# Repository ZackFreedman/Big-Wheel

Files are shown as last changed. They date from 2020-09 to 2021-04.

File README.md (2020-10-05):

# Big Wheel
 3D-printed video control surface

Slapped together in a weekend by Zack Freedman of Voidstar Lab for [a YouTube video! Check it out!](https://www.youtube.com/watch?v=72a85tWOJVY)

Materials:
- 1x each of:
    - Big Ass-Wheel.stl
    - Body.stl
    - Wheel Insert.stl
- 1x of either of the following:
    - One print of Waffle Baseplate Combo.stl
    - One print of Support Waffle.stl and one laser-cut Big Wheel Baseplate.ai
- 7x 10mm M2.5 screws
- 6x M2.5 heat-set inserts, nominal 5mm length
- 1x M2.5 nut
- 14x Cherry MX-compatible keyswitches
- 14x keycaps for keyswitches
- 14x rectifier diodes, such as the 1N4004
- 4x PEC12-compatible rotary encoders with pushbutton, 15mm flatted shaft preferred
- 3x encoder knobs, max. diameter 22mm
- 6x rubber feet, thicker than the head of the M2.5 screws
- 1x Teensy LC, Teensy 3.x, or Teensy 4.0
- Zap-a-Gap or other adhesive that can bond your 3D-printing material
- Lots of wire and heatshrink

Instructions:
1. [Watch video](https://www.youtube.com/watch?v=72a85tWOJVY) to see construction overview
2. Fabricate 3D-printed and laser-cut parts
3. If using laser-cut Big Wheel Baseplate, glue Support Waffle onto the etched side of the Baseplate.
4. Snap keyswitches and encoders into Body
5. Using wiring diagram, build switch matrix. Take care to route wires away from surface that contacts Support Waffle.
6. Connect switch matrix and encoders to Teensy. Take care to leave extra wire!
7. Slide Teensy into its rails. It should fit snugly - if it's loose, add a bit of electrical tape to tighten things up.
8. Connect to computer, load firmware, and test
9. Using a soldering iron, apply heat-set inserts to the bosses on the Body.
10. Mount Waffle and Baseplate combo to the Body using the screws.
11. Apply rubber feet to Baseplate.
12. Slip nut into slot on Big Ass-Wheel and insert screw through side of wheel.
13. Mount Big Ass-Wheel on center encoder and tighten screw. It should turn smoothly but not wobble.
14. Glue Wheel Insert onto Big Ass-Wheel.
15. Mount remaining encoder knobs and keycaps.
16. If desired, modify firmware to bind your preferred commands to the controls.
17. Let Zack know you built the project!

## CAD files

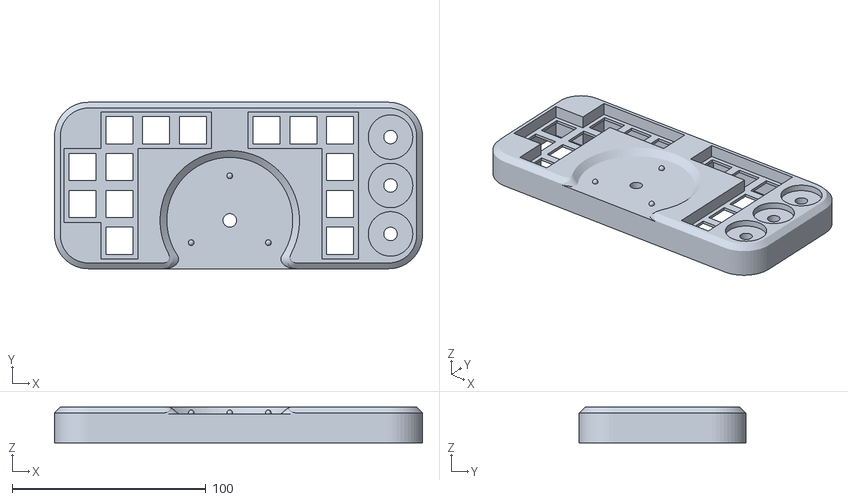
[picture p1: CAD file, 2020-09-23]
Body.stl
190.0 x 86.0 x 18.5

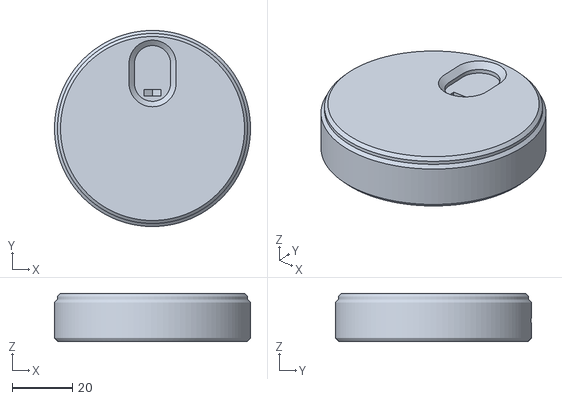
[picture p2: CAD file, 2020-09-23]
Big Ass-Wheel.stl
65.0 x 65.0 x 16.0

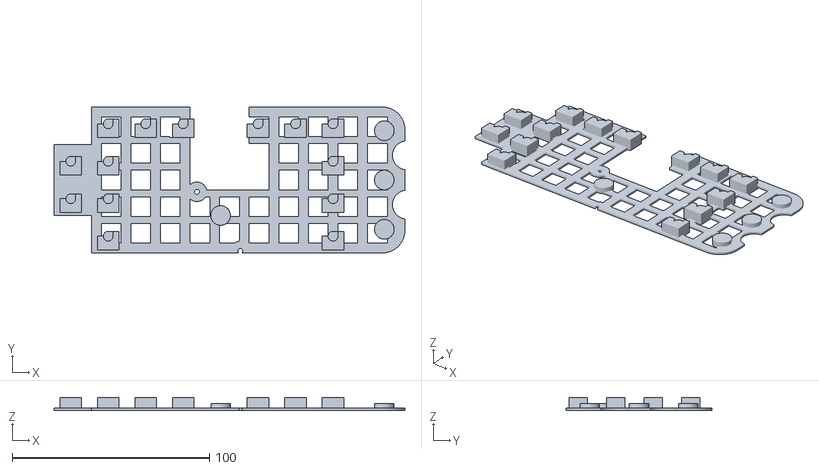
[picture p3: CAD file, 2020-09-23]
Support Waffle.stl
178.0 x 74.0 x 6.50

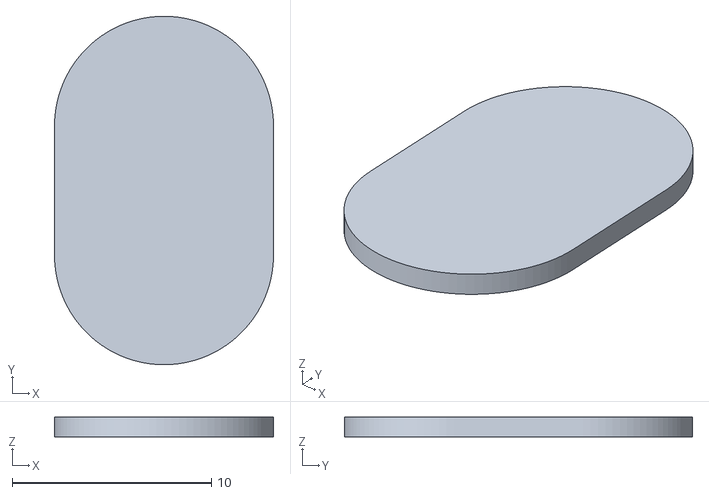
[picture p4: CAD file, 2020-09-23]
Wheel Insert.stl
11.0 x 17.5 x 1.00

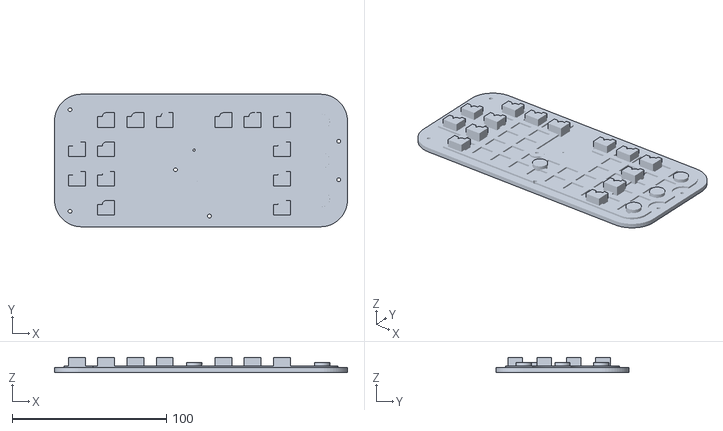
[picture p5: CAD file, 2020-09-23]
Waffle Baseplate Combo.stl
190.0 x 86.0 x 9.50

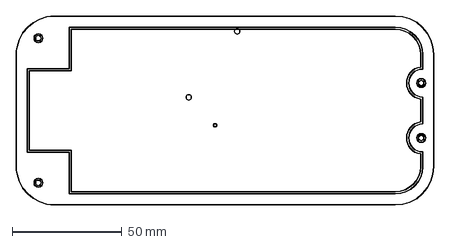
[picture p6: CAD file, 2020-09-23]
Big Wheel Baseplate.dxf
190.0 x 86.0 mm

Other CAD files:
Big Wheel model.f3d

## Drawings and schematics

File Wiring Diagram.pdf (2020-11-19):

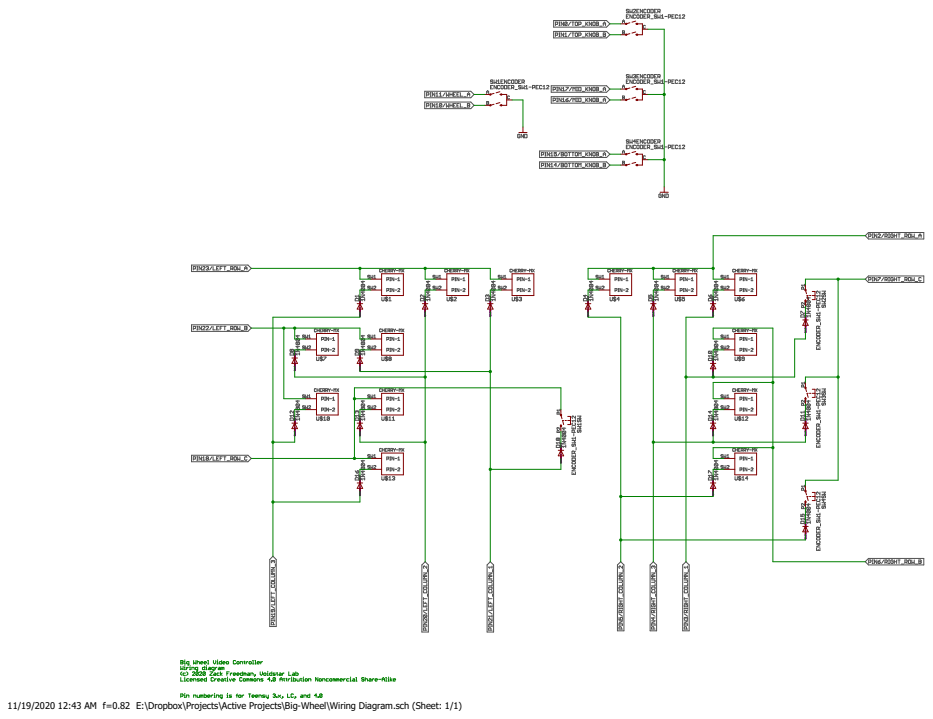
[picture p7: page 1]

11/19/2020 12:43 AM f=0.82 E:\Dropbox\Projects\Active Projects\Big-Wheel\Wiring Diagram.sch (Sheet: 1/1)

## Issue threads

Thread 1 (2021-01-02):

Why wire a keyboard matrix instead of connecting each key to it own Teensy pin?

lvisintini, 2021-01-02:
Hi there @ZackFreedman,

I noticed that you did a keyboard matrix wiring diagram for this project.
After seeing your Teensy video overview I realized I do not understand why you made that design choice, as It would appear that the Teensy has enough digital pins to "service" each of the 14 keys separately.

I think the main benefit of using a matrix is that it reduces the amount of digital pins required to service X number of keys at the cost of making the wiring more complex and requiring diodes to avoid key ghosting.

Given you were time constrained, would it not have been simpler to wire each key directly?

I am only a beginner as far as electronics go, so this question comes out comes a bit out of ignorance and beginner-level research. Apologies in advance for that.

I really your videos. I find them inspiring. Keep them coming.

Cheers

Lvisintini

Liam26, 2021-01-07:
@lvisintini,

I am (obviously) not @ZackFreedman but I thought I might weigh in with my opinion here as to some reasons why he might of done this. Now they may not be correct at all so I’ll be more than happy to be corrected if I’m wrong but here it goes.

Yes it does make the wiring diagram more complex, however, it does drastically reduce the amount of total wires needed. Now this can save you two things mainly:

Time - having fewer wires means less overalls soldering, and the complexity ‘shouldn’t’ really matter if you are following a diagram like Zack was. Therefore less time soldering/faffing more chance of a finished project. (Which is what Zach is saying all the time in his videos, better to ‘cut’ corners and save time to end up with a finished product, rather than it never getting finished!)

Space - this one is a big one for this situation I think, he specifically mentions in his video that he almost had trouble fitting all the wires in with just what he had. Now if he used all the extra wires to make the soldering (and I suppose programming) easier, he might not have gotten it to fit, or possible even had to print a thicker enclosure costing him far more time than just sketching up a matrix diagram before he got the the wiring!

That’s just my thinking around it, so you’re not wrong the teensy could have done it with the amount of pins it had, but the benefits of a matrix in this situation (outlined above) outweighs the downsides (what you stated with the increased wiring complexity)

Anyway it might not have been anything I’ve said I’m only guessing from my point of view so if Zach does get to see this and reply I would be very interested in knowing if these were the reasons or if I’m totally off the mark! But either way I thought I’d share with you as you’d made the effort to ask!

Hope this helps in some way,
Liam

lvisintini, 2021-01-23:
Hi @Liam26. Thanks for this.
I had another look at the cable management in the video and I believe that you are right in both accounts. :)
THX

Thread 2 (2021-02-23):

Teensy collision with mounting stud

kimmellr, 2021-02-23:
There is a collision with the teensy and the venter mounting pose when installing the board.
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

Changing d236 to 16mm should solve this problem with out any conflicts.

Any thoughts?

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

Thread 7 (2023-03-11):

Deletion of lastknobposition for certain knobs

tjseydel, 2023-03-11:
I just finished the build of the keyboard. Thanks for providing all the files @ZackFreedman! It was really fun to make and I learned a lot! =D

When testing the firmware I encountered some unexpected behavior where addition keys were pressed when pressing one of the keys. Also, the top and middle wheels seemed not to be working.

For anyone encountering the same issue, I located where the problem arose. Somehow the lastKnobPositions array values were deleted for the top and middle wheel/encoder which causes repeated execution of these linked knobs and thus additional key presses with every key I pressed.

The array values were deleted in lines 580 & 581:
  for (int i = 0; i < 6; i++)
    lastKnobDeltas[i] = knobDeltas[i];

These lines are not used and can be commented out/deleted to fix the problem.

I have absolutely no idea why these lines cause the array values to be deleted, so if anyone knows, please let me know. I am very curious to see what is causing it.

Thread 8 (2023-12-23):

VBoxMouse.sys crash the PC when unplug USB cable

janxfi, 2023-12-23:
If you have or have ever had Virtualbox installed, when you remove Teensy from the computer, the whole computer crashes. OS is Windows 10.

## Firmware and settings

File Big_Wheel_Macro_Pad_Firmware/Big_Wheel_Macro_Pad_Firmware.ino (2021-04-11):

/*
   "Big Wheel" macro pad firmware
   Copyright Sept. 2020 Zack Freedman of Voidstar Lab
   Licensed Creative Commons 4.0 Noncommercial Share-Alike

   This code is designed to run on this hardware: https://github.com/ZackFreedman/Big-Wheel
   This was used in a YouTube video! Check it out! https://www.youtube.com/watch?v=72a85tWOJVY

   Intended for Teensy LC, but should also work on Teensy 3.X and maybe Teensy 4.0
   These hotkeys and shortcuts are designed to control Premiere Pro, but you do you fam

   REMEMBER: Tools --> USB Type --> Serial + Keyboard + Mouse + Joystick
*/


#include <Encoder.h>
#include "actions.h"
#include "pins.h"

//#define DEBUG_DUMP_EVENTS
//#define DEBUG_DUMP_MATRIX
//#define DEBUG_DUMP_WHEEL_SPEED
//#define DEBUG_PLOT_WHEEL_SPEED
//#define DEBUG_SHUTTLE

Encoder topKnob(topKnobA, topKnobB);
Encoder middleKnob(middleKnobA, middleKnobB);
Encoder lowerKnob(lowerKnobA, lowerKnobB);
Encoder wheel(wheelA, wheelB);

long lastKnobPositions[4] = {0, 0, 0, 0};
int lastKnobDeltas[4];
bool lastSwitchStates[18];
bool debouncedSwitchStates[18];
bool lastDebouncedSwitchStates[18];
elapsedMillis switchDebounceTimestamps[18];
#define switchDebounceTime 50

int lastActions[6];
int allActionsThisFrame[6];
byte actionIndex = 0;

// Used to calculate rotational velocity of big wheel
// 1 detent = 4 pulses in the same direction
// 1 delta = Time between two successive detents, in ms
#define wheelDetentDeltaAverageCount 5  // More detents = smoother but laggier shuttling

// How many ms must elapse without wheel motion before resetting velocity measurements
// wheelTimeout must be > 1000.0 / max(abs(minimumDpsForReverse), minimumDpsForPlay)
#define wheelTimeout 50

// More detents = more predictable but laggier shuttling.
// minimumWheelDetentsToAverage must be <= wheelDetentDeltaAverageCount!
#define minimumWheelDetentsToAverage 2

elapsedMillis timeSinceLastWheelDetent;
long wheelDetentDeltas[wheelDetentDeltaAverageCount];
byte wheelDetentDeltaIndex;  // Used to treat wheelDetentDeltas as a circular buffer
float averageWheelDetentDelta;

// Shuttle states. In normal mode, one big knob detent (4 pulses) moves by 1 frame.
// In other states, a shuttle movement (Hotkeys J or K in Premiere) is in effect.
#define NO_STATE -255 // Shuttle state should never be this
#define STATE_TRIPLE_REVERSE -3
#define STATE_DOUBLE_REVERSE -2
#define STATE_REVERSE -1
#define STATE_NORMAL 0
#define STATE_PLAY 1
#define STATE_DOUBLE_PLAY 2
#define STATE_TRIPLE_PLAY 3

// Minimum speed the wheel must spin to engage a shuttle mode
// DPS = detents per second
// Positive = clockwise
#define minimumDpsForTripleReverse -40
#define minimumDpsForDoubleReverse -30
#define minimumDpsForReverse -20
#define minimumDpsForPlay 25
#define minimumDpsForDoubleSpeed 40
#define minimumDpsForTripleSpeed 50

// To engage a shuttle mode, user must keep turning wheel at the threshold speed,
// or a higher threshold speed, for this many ms.
// Increase to make shuttling more predictable but less responsive.
// No effect on dead stops - wheelTimeout always takes priority.
#define timeUntilSpeedTransition 200

int shuttleState = STATE_NORMAL;
int stateTransitioningInto = NO_STATE;
elapsedMillis speedTransitionTimer;

// Special behavior - turning wheel while holding ALT key (2, 1)
// locks the shuttle into the Play or Reverse state, making viewing more comfortable.
// Any wheel movement, even one detent, unlocks the shuttle and returns to the Normal state.
bool shuttleLocked = false;
elapsedMillis shuttleLockTimer;
#define shuttleLockout 200  //  Wheel movement is ignored for this many ms after locking the shuttle.

// Lock the system by holding ALT (2, 1) and pressing Undo (2, 6)
bool systemLocked = false;  // While the system is locked, no keystrokes are sent over USB.
bool lockKeysLatched = false;  // After locking/unlocking, both keys are disabled until both are released
elapsedMillis ctrlGuardTimer;
// When ALT is pressed, user might be locking system.
// Don't send ALT until this many ms have passed.
#define ctrlGracePeriod 50

// Basic event buffer to collect all applicable shortcut/hotkey actions and send appropriate keystrokes
// Up to 6 actions can be queued, because I don't think the user can realistically hit more.
void queueAction(int action) {
#ifdef DEBUG_DUMP_EVENTS
  Serial.print("Action: ");
  Serial.println(action);
#endif

  if (action != NO_ACTION && actionIndex < 6) {
    allActionsThisFrame[actionIndex] = action;
    actionIndex++;
  }
}

void setup() {
  Serial.begin(9600);

  // Prepare key matrix pins (including encoder clicks)
  // Note that the Encoder library prepares its own pins.
  for (int i = 0; i < 6; i++) {
    pinMode(allButtonRowPins[i], OUTPUT);
    digitalWrite(allButtonRowPins[i], HIGH);
    pinMode(allButtonColumnPins[i], INPUT_PULLUP);
  }
}

void loop() {
  long knobPositions[] = {topKnob.read(), middleKnob.read(), lowerKnob.read(), wheel.read()};
  int knobDeltas[] = {0, 0, 0, 0};
  bool switchStates[] = {0, 0, 0, 0, 0, 0, 0, 0, 0, 0, 0, 0, 0, 0, 0, 0, 0, 0};
  for (int i = 0; i < 6; i++) allActionsThisFrame[i] = NO_ACTION;
  actionIndex = 0;

  // This is necessary to implement shuttle lock
  bool ctrlBeingHeld = debouncedSwitchStates[15];

  if (timeSinceLastWheelDetent >= wheelTimeout) {
#ifdef DEBUG_SHUTTLE
    if (averageWheelDetentDelta != 0)
      Serial.println("Resetting speedometer");
#endif

    for (int i = 0; i < wheelDetentDeltaAverageCount; i++)
      wheelDetentDeltas[i] = 0;
    wheelDetentDeltaIndex = 0;

    averageWheelDetentDelta = 0;

    if (!shuttleLocked && shuttleState != STATE_NORMAL) {
#ifdef DEBUG_SHUTTLE
      Serial.println("Stopping shuttle (timeout)");
#endif

      Keyboard.release(MODIFIERKEY_GUI);

      Keyboard.press(KEY_K);
      Keyboard.release(KEY_K);

      if (ctrlBeingHeld)
        Keyboard.press(MODIFIERKEY_GUI);

      shuttleState = STATE_NORMAL;
    }

    stateTransitioningInto = NO_STATE;
  }


  for (int i = 0; i < 3; i++) {
    digitalWrite(leftButtonRowPins[i], LOW);
    for (int j = 0; j < 3; j++) {
      if (!digitalRead(leftButtonColumnPins[j])) {
#ifdef DEBUG_DUMP_MATRIX
        Serial.print("Left: ");
        Serial.print(i);
        Serial.print(',');
        Serial.print(j);
        Serial.print(" (Button ");
        Serial.print(keyMatrix[0][i][j]);
        Serial.println(')');
#endif

        switchStates[keyMatrix[0][i][j]] = true;
      }
    }
    digitalWrite(leftButtonRowPins[i], HIGH);

    digitalWrite(rightButtonRowPins[i], LOW);
    for (int j = 0; j < 3; j++) {
      if (!digitalRead(rightButtonColumnPins[j])) {
#ifdef DEBUG_DUMP_MATRIX
        Serial.print("Right: ");
        Serial.print(i);
        Serial.print(',');
        Serial.print(j);
        Serial.print(" (Button ");
        Serial.print(keyMatrix[1][i][j]);
        Serial.println(')');
#endif

        switchStates[keyMatrix[1][i][j]] = true;
      }
    }
    digitalWrite(rightButtonRowPins[i], HIGH);
  }

  for (int i = 0; i < 18; i++) {
    if (switchStates[i] != lastSwitchStates[i]) {
      switchDebounceTimestamps[i] = 0;
    }

    if (switchDebounceTimestamps[i] >= switchDebounceTime) {
      lastDebouncedSwitchStates[i] = debouncedSwitchStates[i];
      debouncedSwitchStates[i] = switchStates[i];
    }

    // Perform most actions only on falling edge
    if (debouncedSwitchStates[i] && !lastDebouncedSwitchStates[i]) {
      // Special buttons with multiple roles
      if (i == 15) {
        if (!debouncedSwitchStates[16] && !lockKeysLatched)
          queueAction(switchAssignments[i]);
      }
      else if (i == 16) {
        if (!debouncedSwitchStates[15] && !lockKeysLatched)
          queueAction(switchAssignments[i]);
      }
      else {
#ifdef DEBUG_DUMP_EVENTS
        Serial.print("Queuing action ");
        Serial.println(switchAssignments[i]);
#endif
        queueAction(switchAssignments[i]);
      }
    }
  }

  if (!debouncedSwitchStates[15] && lastDebouncedSwitchStates[15]) {
    Keyboard.release(MODIFIERKEY_GUI);
    Serial.println("Ctrl up");
  }

  if (!systemLocked) {
    for (int i = 0; i < 4; i++) {
      if (abs(knobPositions[i] - lastKnobPositions[i]) >= 4) {
#ifdef DEBUG_DUMP_EVENTS
        Serial.print("Knob ");
        Serial.print(i);
        Serial.print(" ");
        Serial.print(lastKnobPositions[i]);
        Serial.print(" --> ");
        Serial.print(knobPositions[i]);
        Serial.print(" ");
#endif

        if (knobPositions[i] > lastKnobPositions[i]) {
#ifdef DEBUG_DUMP_EVENTS
          Serial.println("CW");
#endif
          knobDeltas[i] = 1;
        }
        else {
#ifdef DEBUG_DUMP_EVENTS
          Serial.println("CCW");
#endif
          knobDeltas[i] = -1;
        }

        lastKnobPositions[i] = knobPositions[i];
      }
    }

    if (knobDeltas[3] != 0) {
      wheelDetentDeltas[wheelDetentDeltaIndex] =
        long(timeSinceLastWheelDetent) * knobDeltas[3];  // Positive: CW, Negative: CCW

      wheelDetentDeltaIndex = (wheelDetentDeltaIndex + 1) % wheelDetentDeltaAverageCount;  // Baby's first circular buffer

      float detentsAveraged = 0;  // I think this needs to be a float or the division op will be truncated
      long runningTotal = 0;
      for (int i = 0; i < wheelDetentDeltaAverageCount; i++) {
        if (wheelDetentDeltas[i] == 0) break;

        detentsAveraged++;
        runningTotal += wheelDetentDeltas[i];
      }

      if (detentsAveraged >= minimumWheelDetentsToAverage) {
        averageWheelDetentDelta = float(runningTotal) / detentsAveraged;

#ifdef DEBUG_DUMP_WHEEL_SPEED
        Serial.print(averageWheelDetentDelta);
        Serial.print("ms --> ");
        Serial.print(1000.0 / averageWheelDetentDelta);
        Serial.println("/sec");
#endif
      }

      timeSinceLastWheelDetent = 0;
    }

    for (int i = 0; i < 4; i++) {
      // CW
      if (knobDeltas[i] > 0) {
        switch (i) {
          case 0:
            queueAction(topKnobAssignments[0]);
            break;
          case 1:
            queueAction(middleKnobAssignments[0]);
            break;
          case 2:
            queueAction(lowerKnobAssignments[0]);
            break;
          case 3:
            if (shuttleState == STATE_NORMAL)
              queueAction(wheelAssignments[0]);
            break;
          default:
            break;
        }
      }
      // CCW
      else if (knobDeltas[i] < 0) {
        switch (i) {
          case 0:
            queueAction(topKnobAssignments[1]);
            break;
          case 1:
            queueAction(middleKnobAssignments[1]);
            break;
          case 2:
            queueAction(lowerKnobAssignments[1]);
            break;
          case 3:
            if (shuttleState == STATE_NORMAL)
              queueAction(wheelAssignments[1]);
            break;
          default:
            break;
        }
      }
    }

    if (debouncedSwitchStates[15]) {  // Lock shuttle if CTRL is held
      if (shuttleLockTimer > shuttleLockout && knobDeltas[3] != 0) {
        Keyboard.release(MODIFIERKEY_GUI);

        Serial.print("Knob position: ");
        Serial.print(knobPositions[3]);
        Serial.print(" Last position: ");
        Serial.println(lastKnobPositions[3]);

        if (knobDeltas[3] == 1) {
          if (shuttleState != STATE_PLAY) {
#ifdef DEBUG_SHUTTLE
            Serial.println("Locking shuttle in Play");
#endif

            shuttleState = STATE_PLAY;
            Keyboard.press(KEY_K);
            Keyboard.release(KEY_K);
            Keyboard.press(KEY_L);
            Keyboard.release(KEY_L);
          }
        }
        else if (knobDeltas[3] == -1) {
          if (shuttleState != STATE_REVERSE) {
#ifdef DEBUG_SHUTTLE
            Serial.println("Locking shuttle in Reverse");
#endif

            shuttleState = STATE_REVERSE;
            Keyboard.press(KEY_K);
            Keyboard.release(KEY_K);
            Keyboard.press(KEY_J);
            Keyboard.release(KEY_J);
          }
        }

        stateTransitioningInto = NO_STATE;
        shuttleLocked = true;
        shuttleLockTimer = 0;

        Keyboard.press(MODIFIERKEY_GUI);
      }
    }
    else {
      if (knobDeltas[3] != 0 && shuttleLocked) {
#ifdef DEBUG_SHUTTLE
        Serial.print("Shuttle unlocked");
#endif

        Keyboard.press(KEY_K);
        Keyboard.release(KEY_K);
        shuttleState = STATE_NORMAL;
        shuttleLocked = false;
      }

      int stateShuttleShouldBeIn = NO_STATE;

      if (averageWheelDetentDelta == 0) {  // If wheel is still, remain locked or return to frame-by-frame scrubbing
        if (shuttleLocked)
          stateShuttleShouldBeIn = shuttleState;
        else
          stateShuttleShouldBeIn = STATE_NORMAL;
      }
      else {  // Wheel is moving and ALT is up. Are we moving fast enough to shuttle?
        float clicksPerSecond = 1000.0 / averageWheelDetentDelta;

        if (clicksPerSecond >= minimumDpsForTripleSpeed)
          stateShuttleShouldBeIn = STATE_TRIPLE_PLAY;
        else if (clicksPerSecond >= minimumDpsForDoubleSpeed)
          stateShuttleShouldBeIn = STATE_DOUBLE_PLAY;
        else if (clicksPerSecond >= minimumDpsForPlay)
          stateShuttleShouldBeIn = STATE_PLAY;
        else if (clicksPerSecond <= minimumDpsForTripleReverse)
          stateShuttleShouldBeIn = STATE_TRIPLE_REVERSE;
        else if (clicksPerSecond <= minimumDpsForDoubleReverse)
          stateShuttleShouldBeIn = STATE_DOUBLE_REVERSE;
        else if (clicksPerSecond <= minimumDpsForReverse)
          stateShuttleShouldBeIn = STATE_REVERSE;
        else
          stateShuttleShouldBeIn = STATE_NORMAL;
      }

      if (shuttleState == stateShuttleShouldBeIn) {  // No need to change state - we're already there
        if (stateTransitioningInto != NO_STATE) {
#ifdef DEBUG_SHUTTLE
          Serial.println("Cancelling transition");
#endif

          speedTransitionTimer = 0;
        }
        stateTransitioningInto = NO_STATE;
      }

      // To switch into a shuttle state, the wheel needs to keep spinning
      // at the appropriate speed or faster for a period of time.
      else if (stateTransitioningInto == stateShuttleShouldBeIn ||
               (stateTransitioningInto < 0 && stateShuttleShouldBeIn < stateTransitioningInto) ||
               (stateTransitioningInto > 0 && stateShuttleShouldBeIn > stateTransitioningInto)) {
        if (speedTransitionTimer >= timeUntilSpeedTransition) {
          if (stateTransitioningInto == STATE_NORMAL) {
            // Any transition to normal mode (frame-by-frame scrubbing) happens immediately.
            // The user must be able to precisely control the playhead at a moment's notice.

#ifdef DEBUG_SHUTTLE
            Serial.println("Stopping shuttle (slowdown)");
#endif

            Keyboard.press(KEY_K);
            Keyboard.release(KEY_K);
          }
          else {
            if (stateTransitioningInto == NO_STATE) {
#ifdef DEBUG_SHUTTLE
              Serial.println("Tried to transition into NO_STATE");
#endif
            }
            else {
              // Successive presses of the J and L keys control shuttle speed in Premiere Pro.
              // Pressing L starts shuttling at normal speed, L again goes to double speed,
              // then J goes back to normal speed, then J twice more reverses
              byte shiftsToPerform = abs(shuttleState - stateTransitioningInto);
              bool shiftDirection = stateTransitioningInto > shuttleState;

#ifdef DEBUG_SHUTTLE
              Serial.print(shiftDirection ? ">>> " : "<<< ");
              Serial.print("Shifting shuttle speed ");
              Serial.print(shiftDirection ? "up " : "down ");
              Serial.print(shiftsToPerform);
              Serial.print(" times, from ");
              Serial.print(shuttleState);
              Serial.print(" to ");
              Serial.println(stateTransitioningInto);
#endif

              if (shuttleLocked)  // We can adjust the speed of a locked shuttle...
                Keyboard.release(MODIFIERKEY_GUI);  // ...but not by pressing CTRL + L

              for (int i = 0; i < shiftsToPerform; i++) {
                if (shiftDirection) {
                  Keyboard.press(KEY_L);
                  Keyboard.release(KEY_L);
                }
                else {
                  Keyboard.press(KEY_J);
                  Keyboard.release(KEY_J);
                }
              }

              if (shuttleLocked)
                Keyboard.press(MODIFIERKEY_GUI);
            }
          }

          shuttleState = stateTransitioningInto;
          stateTransitioningInto = NO_STATE;
        }
      }
      else {
#ifdef DEBUG_SHUTTLE
        Serial.print("Starting transition to ");
        Serial.println(stateShuttleShouldBeIn);
#endif

        stateTransitioningInto = stateShuttleShouldBeIn;
        speedTransitionTimer = 0;
      }
    }

    if (timeSinceLastWheelDetent >= wheelTimeout) {
      for (int i = 0; i < wheelDetentDeltaAverageCount; i++)
        wheelDetentDeltas[i] = 0;
      wheelDetentDeltaIndex = 0;
    }

#ifdef DEBUG_PLOT_WHEEL_SPEED
    // Good for making your own thresholds for shuttling
    if (averageWheelDetentDelta == 0)
      Serial.println(0.0);
    else
      Serial.println(1000.0 / averageWheelDetentDelta);
#endif
  }


  if (!systemLocked) {
    for (int i = 0; i < 6; i++) {
      bool actionAlreadyDone = false;

      if (allActionsThisFrame[i] == NO_ACTION) continue;

      for (int j = 0; j < 6; j++) {
        if (lastActions[j] == allActionsThisFrame[i]) {
          actionAlreadyDone = true;
          break;
        }
      }

      if (!actionAlreadyDone) {
        performAction(allActionsThisFrame[i]);
      }
    }
  }

  if (!debouncedSwitchStates[15] && !debouncedSwitchStates[16])
    lockKeysLatched = false;

  if (debouncedSwitchStates[15] && debouncedSwitchStates[16] && !lockKeysLatched) {
    Keyboard.releaseAll();

    for (int i = 0; i < 6; i++) {
      lastActions[i] = 0;
      allActionsThisFrame[i] = 0;
    }

    if (systemLocked) {
      Serial.println("System unlocked");
      systemLocked = false;
    }
    else {
      Serial.println("System locked");
      systemLocked = true;
    }

    lockKeysLatched = true;
  }

  for (int i = 0; i < 6; i++)
    lastActions[i] = allActionsThisFrame[i];

  for (int i = 0; i < 6; i++)
    lastKnobDeltas[i] = knobDeltas[i];

  for (int i = 0; i < 18; i++)
    lastSwitchStates[i] = switchStates[i];

#ifdef DEBUG_PLOT_WHEEL_SPEED
  // Don't kick computer in the crotch with firehose of USB traffic
  delay(10);
#endif
}

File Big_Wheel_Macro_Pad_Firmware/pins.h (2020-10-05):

#define topKnobA 0
#define topKnobB 1
#define middleKnobA 17
#define middleKnobB 16
#define lowerKnobA 15
#define lowerKnobB 14
#define wheelA 11
#define wheelB 10

const byte allKnobPins[] = {topKnobA, topKnobB,
                      middleKnobA, middleKnobB,
                      lowerKnobA, lowerKnobB,
                      wheelA, wheelB
                     };

// To simplify wiring, keys are actually in two separate matrices.
// The Teensy has like a million GPIO's, I can sacrifice four.
#define leftButtonsA 23
#define leftButtonsB 22
#define leftButtonsC 18
#define leftButtons1 21
#define leftButtons2 20
#define leftButtons3 19

#define rightButtonsA 2
#define rightButtonsB 6
#define rightButtonsC 7
#define rightButtons1 3
#define rightButtons2 5
#define rightButtons3 4

const byte leftButtonRowPins[] = {leftButtonsA, leftButtonsB, leftButtonsC};
const byte rightButtonRowPins[] = {rightButtonsA, rightButtonsB, rightButtonsC};

const byte allButtonRowPins[] = {leftButtonsA, leftButtonsB, leftButtonsC,
                           rightButtonsA, rightButtonsB, rightButtonsC
                          };

const byte leftButtonColumnPins[] = {leftButtons1, leftButtons2, leftButtons3};
const byte rightButtonColumnPins[] = {rightButtons1, rightButtons2, rightButtons3};

const byte allButtonColumnPins[] = {leftButtons1, leftButtons2, leftButtons3,
                              rightButtons1, rightButtons2, rightButtons3
                             };

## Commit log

2020-09-23 Initial commit
    What do you call a baby turkey?
    A goblet.
    [Big Ass-Wheel.stl, Big Wheel Baseplate.dxf, Big Wheel model.f3d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]
2020-10-05 Added documentation
    - Added URL's to sketch
    - Added BOM and instructions to Readme
    - Added wiring diagram
    [Wiring Diagram.sch]
2020-11-19 Fixed error in wiring diagram
    BOTTOM_KNOB_B was labeled as Pin 10, should be Pin 14. Thanks to @CarlesM on Twitter for spotting.
    [Wiring Diagram.sch]
2021-04-09 Update Big_Wheel_Macro_Pad_Firmware.ino
    Changed the max value that the actionIndex can reach from 6, to 5.
    This would cause a crash if more than 6 actions during a frame since the code would try to write a seventh value to a 6 element array
    [Big_Wheel_Macro_Pad_Firmware.ino]
